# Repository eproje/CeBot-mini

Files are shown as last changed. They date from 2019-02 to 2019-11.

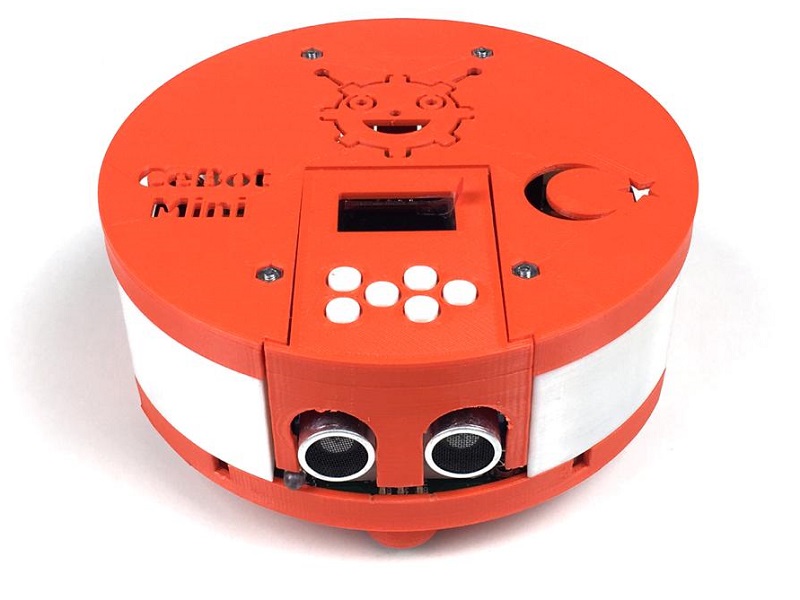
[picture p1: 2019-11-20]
images/cebot_01.jpg

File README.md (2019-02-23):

# CeBot-mini

<br>
<b>CeBot-mini PIN-MAP</b> 
<br>
Microcontroller: ATMEGA328P-AU (arduino UNO compatible)
<br>
<pre>
(RX)  	- D0 is referred to as Pin 0 (DIGITAL)<br>
(TX)  	- D1 is referred to as Pin 1 (DIGITAL)<br>
(IRIN)	- D2 is referred to as Pin 2 (DIGITAL)<br>
(ECHO)	- D3 is referred to as Pin 3 (DIGITAL)<br>
(DIR-M2)- D4 is referred to as Pin 4 (DIGITAL)<br>
(PWM-M2)- D5 is referred to as Pin 5 (DIGITAL)<br>
(PWM-M1)- D6 is referred to as Pin 6 (DIGITAL)<br>
(DIR-M1)- D7 is referred to as Pin 7 (DIGITAL)<br>
(BUZZER)- D8 is referred to as Pin 8 (DIGITAL)<br>
(SERVO1)- D9 is referred to as Pin 9 (DIGITAL)<br>
(SERVO2)- D10 is referred to as Pin 10 (DIGITAL)<br>
(TRIG)  - D11 is referred to as Pin 11 (DIGITAL)<br>
(IROUT) - D12 is referred to as Pin 12 (DIGITAL)<br>
(PIXEL) - D13 is referred to as Pin 13 (DIGITAL)<br>
(SN0) 	- A0 is referred to as Pin 14 (ANALOG)<br>
(SN1) 	- A1 is referred to as Pin 15 (ANALOG)<br>
(S0)  	- A2 is referred to as Pin 16 (DIGITAL)<br>
(S1)  	- A3 is referred to as Pin 17 (DIGITAL)<br>
(SDA) 	- A4 is referred to as Pin 18 (DIGITAL)<br>
(SDC) 	- A5 is referred to as Pin 19 (DIGITAL)<br>
(LDR) 	- A6 is referred to as Pin 20 (ANALOG)<br>
(BTN) 	- A7 is referred to as Pin 21 (ANALOG)<br>
</pre>

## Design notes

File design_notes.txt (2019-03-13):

24022019 - 
	1. sarj akimi yukseltildi bunun icin R12 direnci 4k7 yerine 2k2 olarak kullannildi
	2. motorlar tam guc testine alindi. DC-DC ceviricinin yeterli gelmedigi goruldu
	Cozum olarak VIN ile VCC arasina diyot eklenerek batarya yedeklemesi yapildi
	Gercek olarak tasarimda cift DC-DC kullanmak gerekiyor. 
23022019 - GITHUB sayfasi olusturuldu
https://github.com/eproje/CeBot-mini

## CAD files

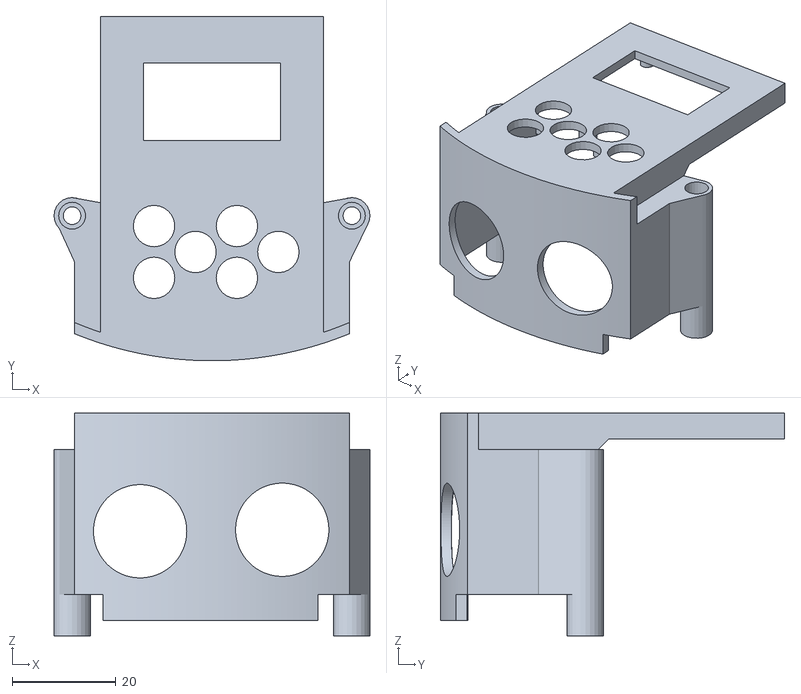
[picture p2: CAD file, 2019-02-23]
3D_files/files/CM-ekran.stl
61.0 x 66.5 x 43.0

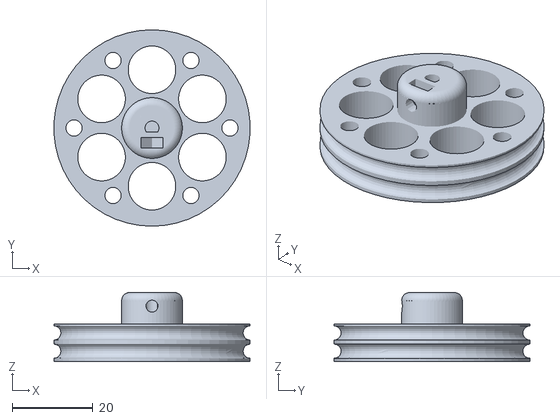
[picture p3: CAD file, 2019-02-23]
3D_files/files/CM_teker-2ad.stl
48.4 x 48.5 x 17.1

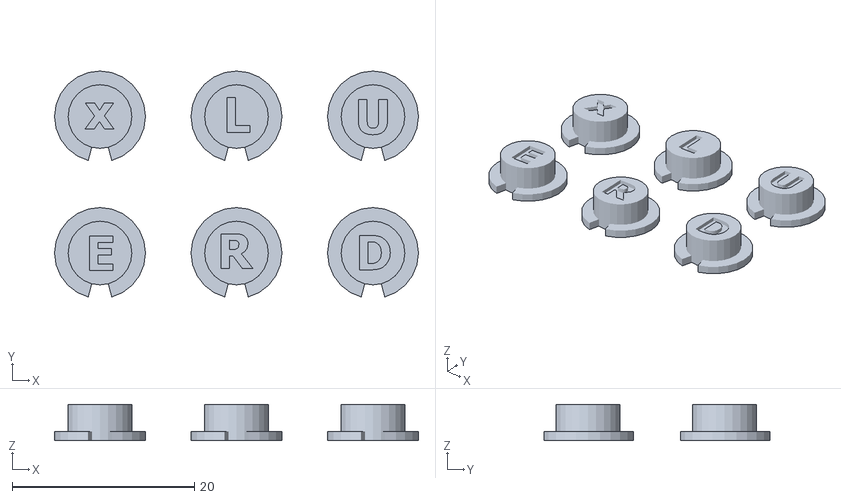
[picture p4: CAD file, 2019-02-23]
3D_files/files/CM_butonlar.stl
40.0 x 24.8 x 4.00

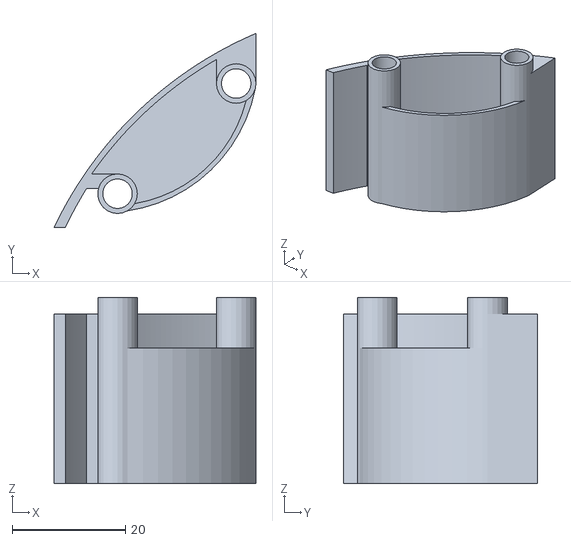
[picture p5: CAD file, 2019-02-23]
3D_files/files/CM_far4.stl
35.7 x 34.4 x 33.0

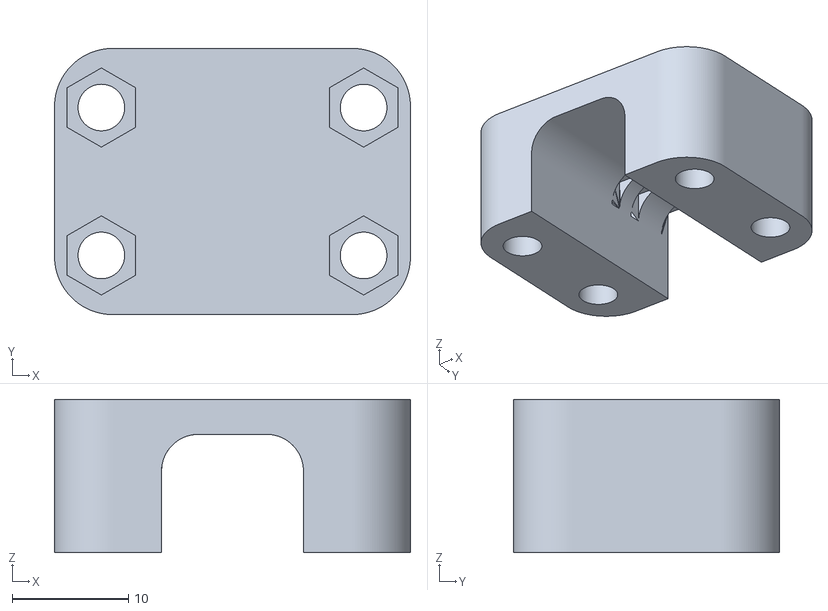
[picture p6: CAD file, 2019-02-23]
3D_files/files/CM_Mottutucu-2ad.stl
30.6 x 22.9 x 13.2

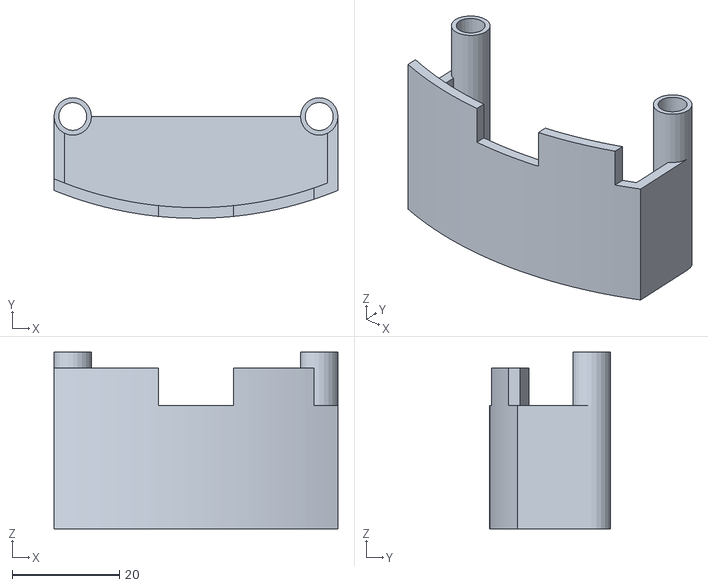
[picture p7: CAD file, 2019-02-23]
3D_files/files/CM_arka.stl
53.0 x 22.5 x 33.0

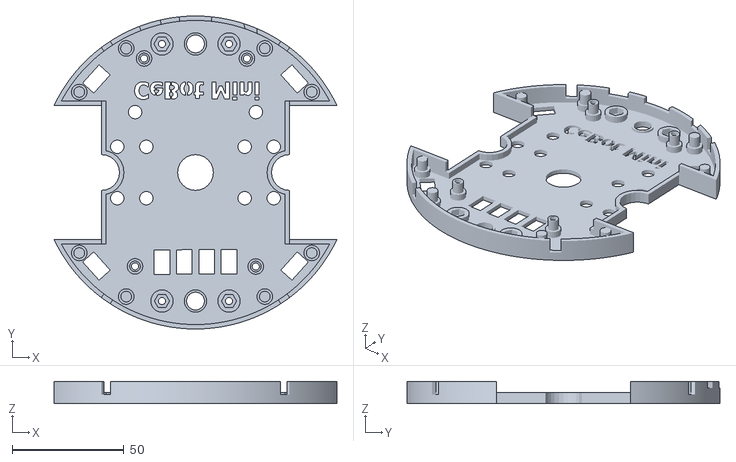
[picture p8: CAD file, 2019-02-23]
3D_files/files/CM-alt.stl
126.5 x 140.0 x 10.0

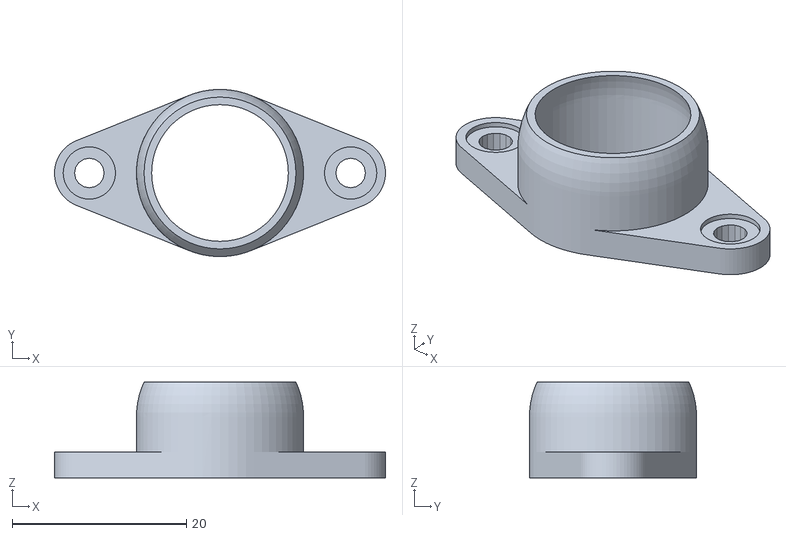
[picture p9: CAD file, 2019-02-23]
3D_files/files/CM_sarhosteker-2ad.stl
38.0 x 19.2 x 11.0

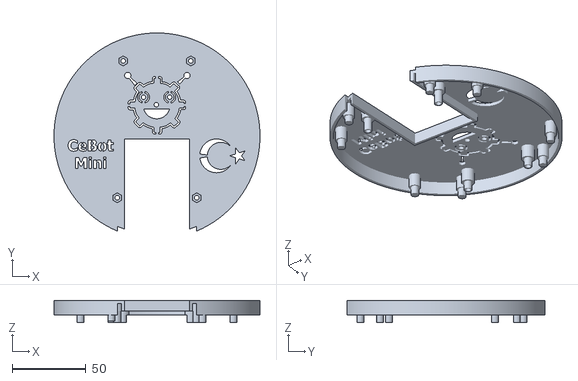
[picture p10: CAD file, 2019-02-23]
3D_files/files/CM_ust.stl
140.0 x 134.6 x 15.0

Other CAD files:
3D_files/files/CM_far1.stl
3D_files/files/CM_far3.stl
3D_files/files/CM_far2.stl

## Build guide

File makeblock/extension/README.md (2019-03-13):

# CeBot-mini MAKEBLOCK EXTENSION Files

[TR]
Bu klasörde yer alan doslayarı, MAKEBLOCK programının kurulu olduğu dizin içerisinde yer alan .../ext/libraries/ klasorune 
CeBot-mini isimli bir klasor açarak kopyalayınız.
Örnek:
D:\Elt_Soft\mBlock\ext\libraries\CeBot_Mini

[EN]

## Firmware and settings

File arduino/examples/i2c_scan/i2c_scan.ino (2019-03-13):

#include <Wire.h>


void setup()
{
  Wire.begin();

  Serial.begin(9600);
  Serial.println("\nI2C Scanner");
}


void loop()
{
  byte error, address;
  int nDevices;

  Serial.println("Scanning...");

  nDevices = 0;
  for(address = 1; address < 127; address++ ) 
  {
    // The i2c_scanner uses the return value of
    // the Write.endTransmisstion to see if
    // a device did acknowledge to the address.
    Wire.beginTransmission(address);
    error = Wire.endTransmission();

    if (error == 0)
    {
      Serial.print("I2C device found at address 0x");
      if (address<16) 
        Serial.print("0");
        Serial.print(address,HEX);
        Serial.println("  !");

      nDevices++;
    }
    else if (error==4) 
    {
      Serial.print("Unknow error at address 0x");
      if (address<16) 
        Serial.print("0");
        Serial.println(address,HEX);
    }    
  }
  if (nDevices == 0)
    Serial.println("No I2C devices found\n");
  else
    Serial.println("done\n");

  delay(5000);           // wait 5 seconds for next scan
}

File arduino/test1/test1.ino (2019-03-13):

#include "CeBotmini.h"

CeBotmini robot1;

int sayac=0;
void setup() {
  // put your setup code here, to run once:

}

void loop() {
  // put your main code here, to run repeatedly:
  robot1.display.setTextSize(1);
  /*
  display.setTextSize(1);
  display.setTextColor(WHITE);
  display.setCursor(1,0);
  display.println("sayac");
  display.display();
  delay(100);
  */
}
